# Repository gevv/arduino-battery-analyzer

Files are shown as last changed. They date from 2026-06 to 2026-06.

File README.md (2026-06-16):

# Arduino Battery Analyzer

This project is an Arduino-based battery analyzer designed for measuring battery capacity and estimating internal resistance + constant current. It can be used not only for single-cell 18650 Li-ion batteries, but also for other rechargeable batteries and battery packs up to approximately 20 V, depending on the voltage divider, load resistor, MOSFET, cooling, and calibration settings.

Related article/project page:
https://320volt.com/arduino-pil-analizoru/

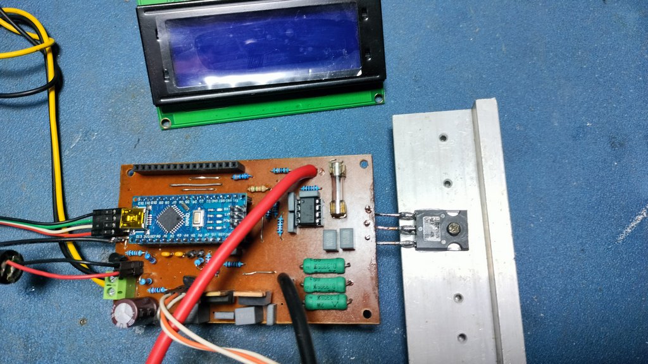
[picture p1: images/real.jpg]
Arduino Battery Analyzer Prototype


## Features

* Power requirements: 12 V, 250 mA
* Input voltage: 0.8-20 V, measurement resolution 0.01 V
* Can be adapted for other batteries or battery packs up to approximately 20 V
* Battery  Capacity meter
* Constant current load
* Internal resistance meter
* Discharge current: 0,01-2,55 A
* Control: 4 buttons, 20x4 character LCD
* LM35 Fan control (optinal)

## LCD Menu and Measurement Screens

The project uses a 20x4 character LCD screen for menu navigation, capacity measurement, constant current load testing, internal resistance measurement, and device settings.

### Main Menu

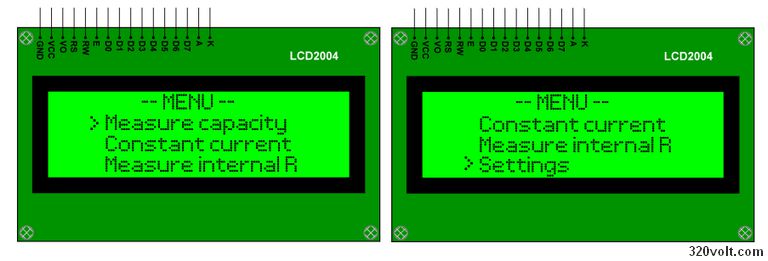
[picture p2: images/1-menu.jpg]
Main Menu


### Capacity Measurement

This mode is used to discharge the connected battery with a selected current and calculate the measured capacity.

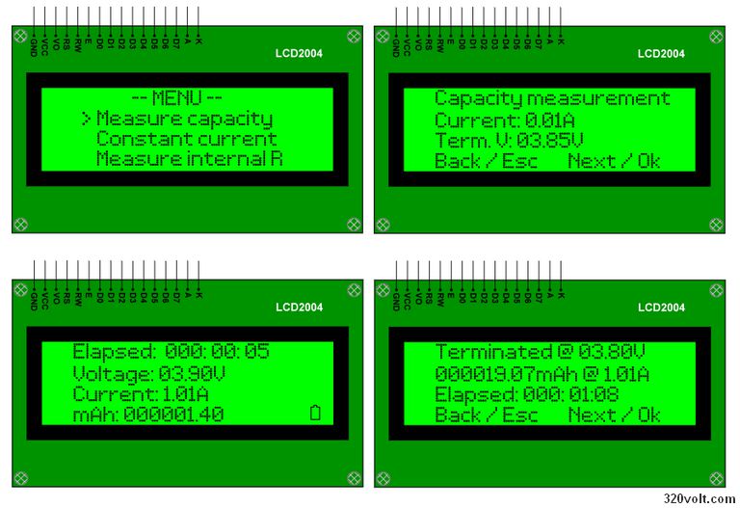
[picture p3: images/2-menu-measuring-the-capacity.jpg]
Capacity Measurement Menu


### Constant Current Mode

This mode allows the circuit to operate as a constant current electronic load.

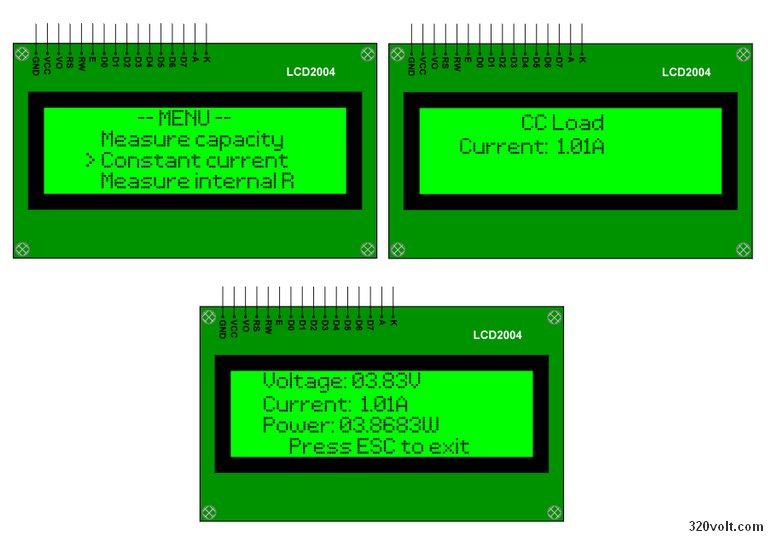
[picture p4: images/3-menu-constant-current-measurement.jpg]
Constant Current Measurement


### Internal Resistance Measurement

This mode estimates the internal resistance of the battery by comparing voltage values under different load current conditions.

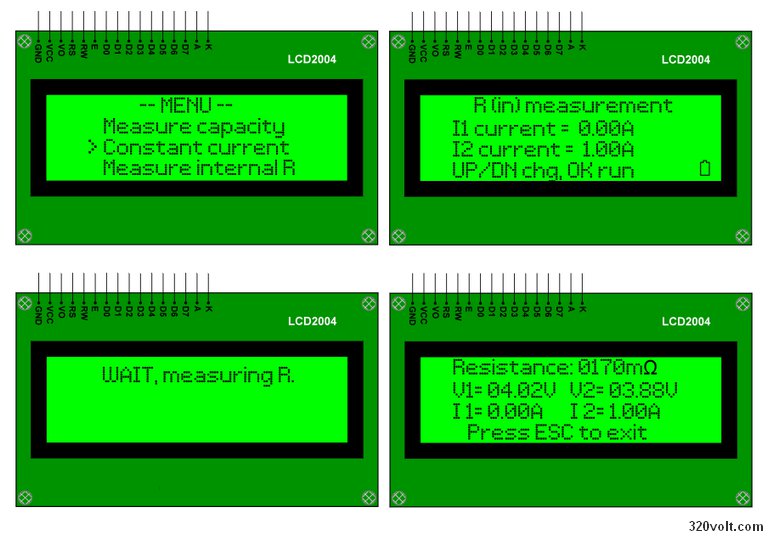
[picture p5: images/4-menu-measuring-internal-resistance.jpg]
Internal Resistance Measurement


### Settings Menu

The settings menu includes options such as sound, ADC offset compensation, and saving calibration values to EEPROM.

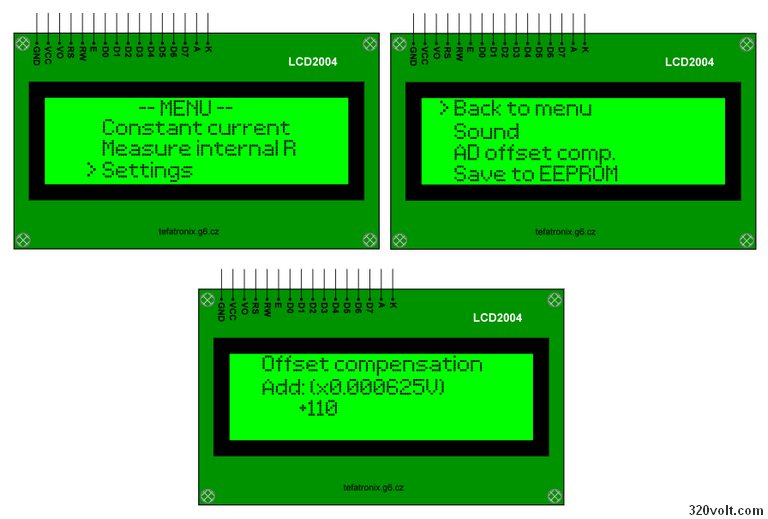
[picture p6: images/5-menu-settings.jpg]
Settings Menu


## Hardware

* Arduino Nano / ATmega328P
* Battery holder or external battery connection terminals
* Load resistors
* MOSFET driver circuit
* LCD screen
* Voltage measurement divider circuit
* Current measurement circuit
* Cooling fan for load resistors and MOSFET

## Schematic

The schematic below shows the Arduino Nano connections, LCD interface, voltage divider, MOSFET load stage, current sensing section, buzzer, fan output, and power supply regulators.

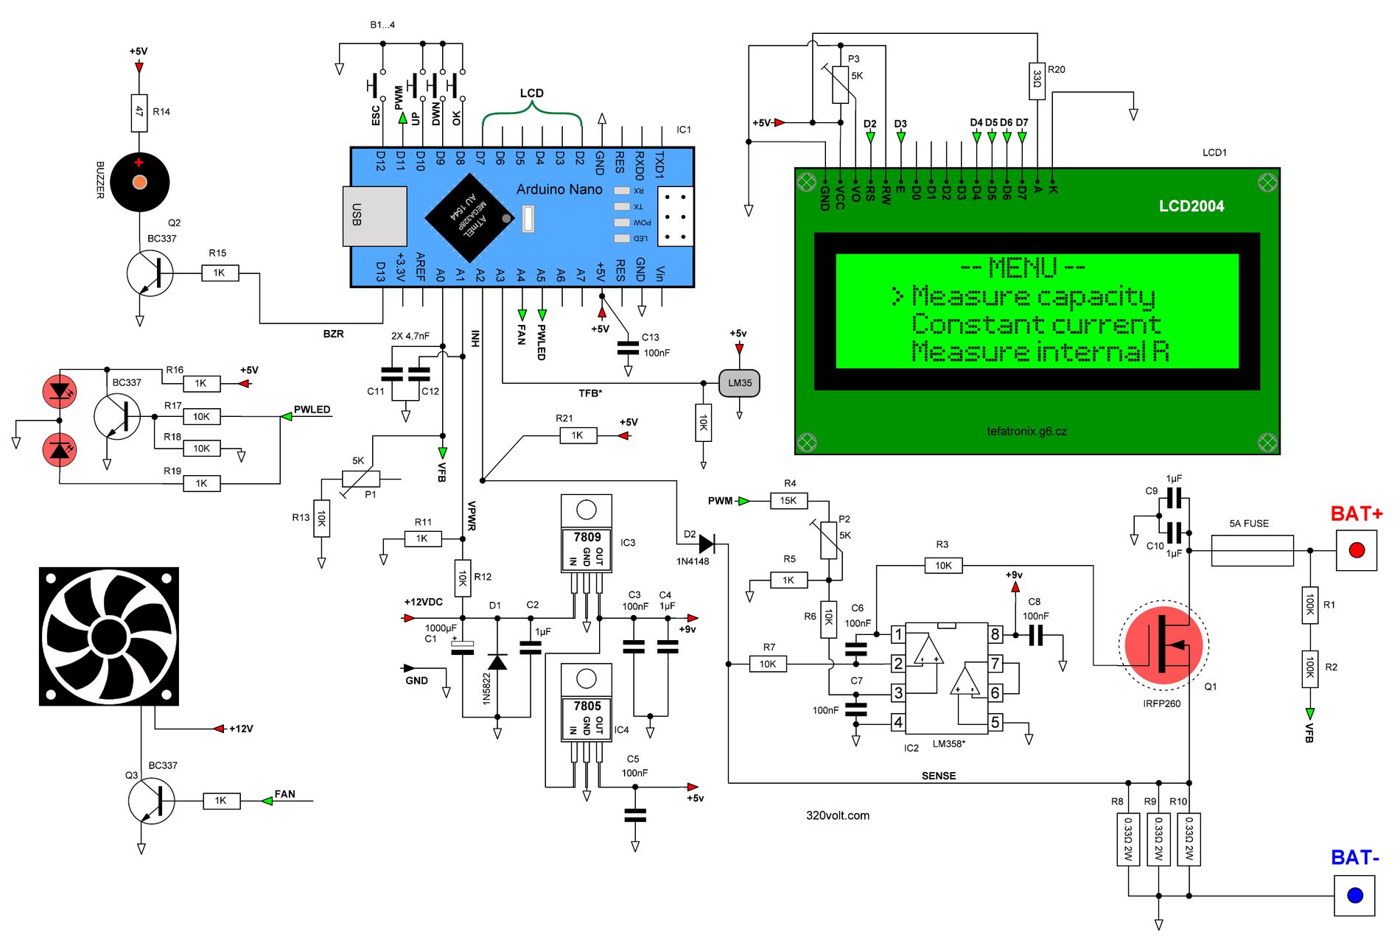
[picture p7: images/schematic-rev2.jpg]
Arduino Battery Analyzer Schematic


## PCB Layout

The PCB layout includes the Arduino Nano, LCD connector, MOSFET load section, resistor load bank, voltage measurement input, current sense path, fan output, and power supply section.

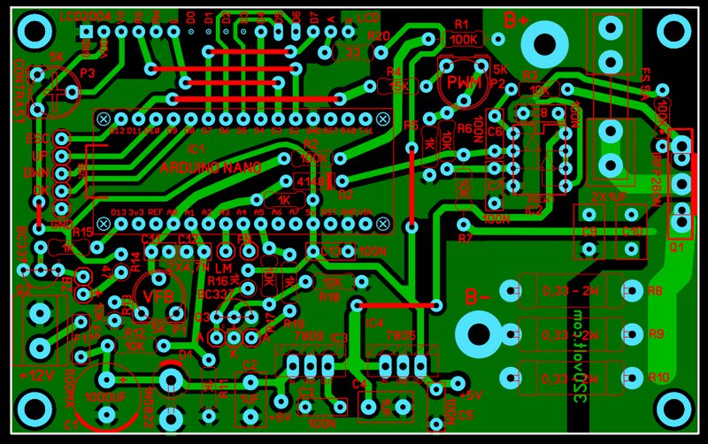
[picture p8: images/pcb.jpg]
Arduino Battery Analyzer PCB


## Important Note

This project is for educational and testing purposes only. When working with Li-ion batteries, lead-acid batteries, NiMH packs, or other rechargeable batteries, caution must be exercised against short circuits, overcurrent, reverse polarity, overheating, and incorrect voltage divider calibration.

For battery voltages higher than a single Li-ion cell, the voltage divider, load resistor power rating, MOSFET voltage/current rating, heat dissipation, and firmware calibration values must be checked and adjusted before use.

The maximum usable battery voltage depends on the voltage divider ratio, ADC input limits, MOSFET rating, load resistor power rating, fuse rating, PCB trace current capacity, and cooling performance.

## Credits

Original project:
https://tefatronix.g6.cz/display.php?page=batmeter

Original author:
F. Štefanec

Related article/project page:
https://320volt.com/arduino-pil-analizoru/

This Arduino Nano version is based on / adapted from the original rechargeable battery analyzer project.

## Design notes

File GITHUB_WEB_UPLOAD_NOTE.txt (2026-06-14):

GitHub Web Upload Note

Do not upload this ZIP file as a single file if you want GitHub to display the project folders.

1. Extract this ZIP on your computer.
2. Open the extracted folder.
3. On GitHub, create a new repository.
4. Use Add file > Upload files.
5. Drag and drop the CONTENTS of this folder into GitHub.
6. Commit the upload.

Recommended repository name:
arduino-battery-analyzer

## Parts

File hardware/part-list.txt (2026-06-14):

*
* Name	Value	Comment
*
C1	1000uF	16V
C2	1uF	Polyester, non-polarized
C3	100nF	
C4	1uF	Polyester, non-polarized
C5	100nF	
C6	100nF	Multilayer
C7	100nF	Multilayer
C8	100nF	
C9	1uF	Polyester, non-polarized
C10	1uF	Polyester, non-polarized
C11	4,7nF	MULTILAYER
C12	4,7nF	MULTILAYER
C13	100nF	
D1	1N5822	
D2	1N4148	
F1	500MA	FUSE OR JUMPER
F2	5A	    FUSE OR JUMPER (1.5mm)
B1	Button
B2	Button
B3	Button
B4	Button
IC1	ARDUINO NANO	
IC2	LM358	
IC3	7809	TO220
IC4	7805	TO220
LCD	20X4	LCD2004
P1	5K	TRIMPOT
P2	5K	TRIMPOT
P3	5K	TRIMPOT
Q1	IRFP260	
Q2	BC337	
Q3	BC337	
R1	100K	%1
R2	100K	%1
R3	10K	
R4	15K	%1
R5	1K	%1
R6	10K	%1
R7	10K	%1
R8	0.33 OHM	2W
R9	0.33 OHM	2W
R10	0.33 OHM 	2W
R11	1K	%1
R12	10K	%1
R13	10K	%1
R14	47 OHM	
R15	1K	
R16	1K	
R17	10K	
R18	10K	
R19	1K	
R20	33 OHM	

OPTINAL
LM35 + 1OK (OUT/GND)
BC337 + 1K (FAN)

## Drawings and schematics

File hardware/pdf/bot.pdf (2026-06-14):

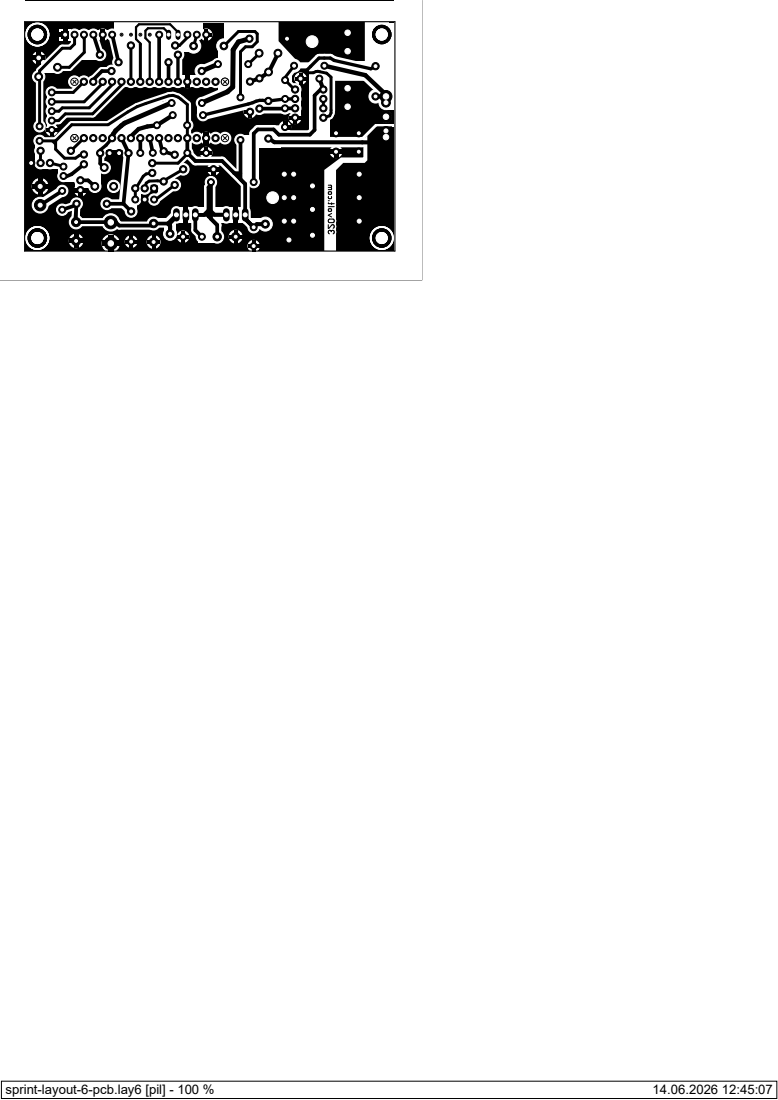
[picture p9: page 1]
sprint-layout-6-pcb.lay6 [pil] - 100 %

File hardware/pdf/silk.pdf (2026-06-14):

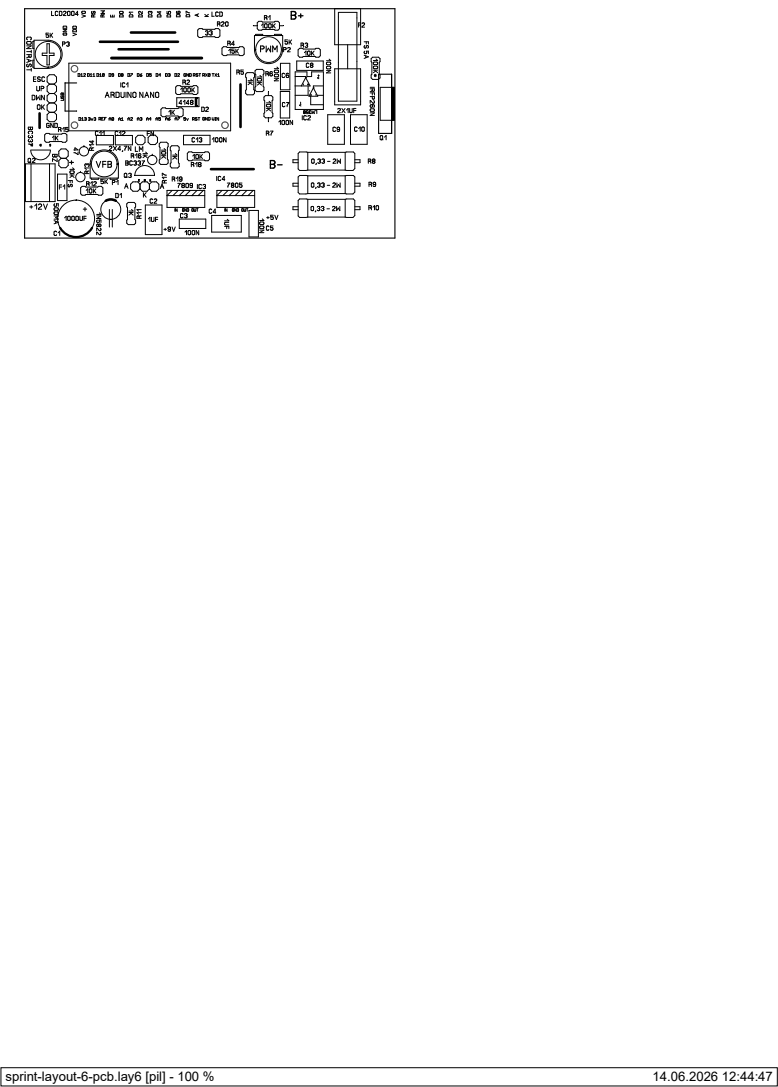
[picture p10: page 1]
sprint-layout-6-pcb.lay6 [pil] - 100 %

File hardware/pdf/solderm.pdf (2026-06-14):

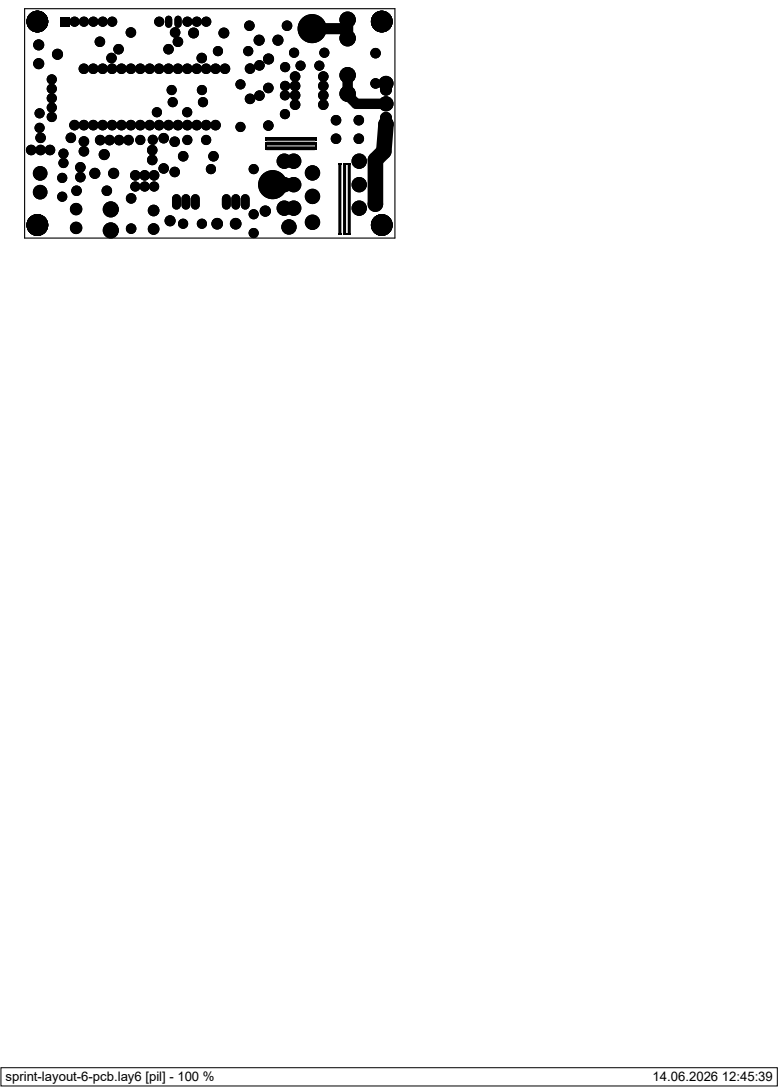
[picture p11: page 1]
sprint-layout-6-pcb.lay6 [pil] - 100 %

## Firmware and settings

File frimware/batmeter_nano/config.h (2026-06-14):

/**
    Battery analyzer - Arduino Nano port
    Original: (c) 2016-2017 F. Štefanec
    Arduino Nano port: 2024

    ATmega328P pin mapping is IDENTICAL between the original board and Arduino Nano.
    Only the build system changes (AVR-C → Arduino framework).

    Original schematic pin assignments are preserved 1:1.
**/

#ifndef CONFIG_INCLUDED
#define CONFIG_INCLUDED

/// Language
//#define LANG_CZ
#define LANG_EN

// ─── LCD pin / port definitions ──────────────────────────────────────────────
// LCD is connected to PORTD (data + control), same as original schematic.
#define LCD_DPORT  PORTD
#define LCD_CPORT  PORTD
#define LCD_DDDR   DDRD
#define LCD_CDDR   DDRD
#define LCD_E      PD3    // Arduino D3
#define LCD_RS     PD2    // Arduino D2
#define LCD_D4     PD4    // Arduino D4
#define LCD_D5     PD5    // Arduino D5
#define LCD_D6     PD6    // Arduino D6
#define LCD_D7     PD7    // Arduino D7
#define DISPSIZE   6      // 20x4 display, do not modify

// ─── Keyboard ────────────────────────────────────────────────────────────────
#define DEBOUNCE_VAL   6    // 6 × 4ms ≈ 24 ms
#define REPEAT_PERIOD  30   // 30 × 4ms = 120 ms
#define REPEAT_DELAY   250  // 250 × 4ms = 1000 ms

// ─── ADC / measurement ───────────────────────────────────────────────────────
#define DEFAULT_OFFSET_COMP  110
#define RIN_PREAVG_COUNT     8
#define CAP_PREAVG_COUNT     32
#define DEFAULT_SETTINGS     0

// ─── Temperature / LM35 ──────────────────────────────────────────────────────
/// Uncomment the next line only if the LM35 sensor is installed on TFB / A3.
/// If the sensor is not installed, leaving it enabled can cause false thermal shutdown.
//#define LM35_INSTALLED
#define TEMP_AD_FAN_START  512   // ~55 °C
#define TEMP_AD_FAN_STOP   446   // ~48 °C
#define TEMP_AD_FAULT      725   // ~78 °C  → emergency halt

// ─── Button pins (PORTB) ─────────────────────────────────────────────────────
// Original: PINB / PORTB
#define BTN_PIN   PINB
#define BTN_PORT  PORTB

#define BTN_ESC_PIN   PB4   // Arduino D12
#define BTN_UP_PIN    PB2   // Arduino D10
#define BTN_DOWN_PIN  PB1   // Arduino D9
#define BTN_OK_PIN    PB0   // Arduino D8

// ─── INHIBIT pin (PC2 = Arduino A2) ──────────────────────────────────────────
#define INHIBIT_PIN   PC2
#define INHIBIT_PORT  PORTC
#define INHIBIT_DDR   DDRC

// ─── Buzzer (PB5 = Arduino D13) ──────────────────────────────────────────────
// NOTE: D13 also has the built-in LED. Disconnect or ignore LED flicker.
#define BUZZER_PIN   PB5
#define BUZZER_PORT  PORTB
#define BUZZER_DDR   DDRB

// ─── ADC channel mux values ──────────────────────────────────────────────────
#define MUX_BATT_VOLTAGE    (0)                   // ADC0 = A0
#define MUX_SUPPLY_VOLTAGE  (1<<MUX0)             // ADC1 = A1
#define MUX_TEMPERATURE     (0b011)               // ADC3 = A3

// ─── Fan (PC4 = Arduino A4) ──────────────────────────────────────────────────
#define FAN_PIN   PC4
#define FAN_PORT  PORTC
#define FAN_DDR   DDRC

// ─── Power LED (PC5 = Arduino A5) ────────────────────────────────────────────
#define LED_PIN   PC5
#define LED_DDR   DDRC
#define LED_PORT  PORTC

// ─── Beep lengths (timer 0 ticks @ 2 kHz / 8 = 250 Hz effective) ─────────────
#define BEEP_LEN_BUTTON    10
#define BEEP_LEN_FINISHED  250
#define BEEP_LEN_REPEAT    5
#define BEEP_LEN_START     5

#endif // CONFIG_INCLUDED

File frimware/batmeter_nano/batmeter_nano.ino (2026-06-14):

/**
Battery Analyzer v1.4.0 — Arduino Nano port

Original code: (c) 2016-2017 F. Štefanec

Arduino Nano port: 2026

This firmware is an Arduino Nano port / modified version of the
original rechargeable battery analyzer project.

Original project page: https://tefatronix.g6.cz/display.php?page=batmeter

Original author: F. Štefanec

Original code license: GNU GPL v2 or later, unless otherwise noted by the original author.

Related article/project page: https://320volt.com/arduino-pil-analiz-cihazi

Hardware note:
  Hardware connections are intended to match the original ATmega328P
  design. Arduino Nano uses the same ATmega328P MCU, so register names
  such as TCCR0B, OCR2A, ADMUX, etc. remain unchanged.

Changes from original:
  - main() -> setup() + loop()
  - _delay_ms/_delay_us -> wait_ms()/delayMicroseconds()
  - avr/io.h / util/delay.h -> Arduino.h
  - avr/eeprom.h functions are still used directly
  - avr/pgmspace.h PROGMEM is still used directly
  - Watchdog: wdt.h included for Arduino-safe macros
  - ISR declarations retained as-is

Pin summary (Arduino Nano digital / analog labels):
  D2  = LCD RS
  D3  = LCD E
  D4-D7 = LCD data

  D8  = BTN OK
  D9  = BTN DOWN
  D10 = BTN UP
  D12 = BTN ESC

  D11 = PWM output (OC2A, PB3)
  D13 = Buzzer (PB5) - shares built-in LED

  A0  = Battery voltage ADC
  A1  = Supply voltage ADC
  A2  = INHIBIT output
  A3  = Temperature (LM35) ADC
  A4  = FAN output
  A5  = Power LED output

*/


// ─── Core AVR headers (available inside Arduino framework) ───────────────────
#include <Arduino.h>
#include <avr/interrupt.h>
#include <avr/eeprom.h>
#include <avr/pgmspace.h>
#include <avr/wdt.h>
#include <util/atomic.h>


// Save reset cause and disable watchdog as early as possible.
// This is important on Arduino Nano/Optiboot-style bootloaders when WDT is used.
uint8_t mcusr_mirror __attribute__((section(".noinit")));
void get_mcusr(void) __attribute__((section(".init3")));
void get_mcusr(void)
{
    mcusr_mirror = MCUSR;
    MCUSR = 0;
    wdt_disable();
}

// ─── Project headers ─────────────────────────────────────────────────────────
#include "config.h"
#include "global_defines.h"
#include "lcd.h"
#include "string_table.h"
#include "lcd_customchars.h"
#include "digits.h"
#include "menu.h"

// ─── Omega character position in CGRAM ───────────────────────────────────────
#define OMEGA_CHAR 5

// ════════════════════════════════════════════════════════════════════════════
//  GLOBAL VARIABLES  (identical to original main.h)
// ════════════════════════════════════════════════════════════════════════════

uint8_t x, y, z;

uint8_t ad_preavg_count;
volatile uint8_t stat, stat2;
volatile uint8_t discharge_stop_request = 0;
volatile uint8_t temp_fault_request = 0;
uint8_t settings;
uint8_t submenu_stat = 0;
uint8_t field = 0;
uint8_t menu_pos = 1, old_menu_pos = 1, menu_pos2, old_menu_pos2;
volatile uint8_t beep_counter, old_beep_counter;
uint8_t rin_current_choice = 0;
const uint8_t rin_current1[10] PROGMEM = {0,  25,   0,  50,   0, 100, 150,   0,  50,   0};
const uint8_t rin_current2[10] PROGMEM = {25, 50,  50, 100, 100, 200, 250, 200, 250, 250};
uint8_t led_state1 = 2;
uint8_t led_state2 = 0;
volatile uint16_t led_blink_time = 0;
uint8_t last_option = 0;
volatile uint8_t fan_control = 0;

volatile uint8_t  seconds;
volatile uint8_t  minutes;
volatile uint8_t  hours;
unsigned long long elapsed_secs = 0;
uint8_t tim0_sw_pre;
uint8_t tim0_even = 0;
uint16_t tim0_blink_counter = 0;

uint8_t buttons_old_pin;
volatile uint8_t buttons;
uint8_t buttons_old;
uint8_t buttons_pressed;
uint8_t button_repeat_counter;
uint8_t btn_debounce = 0;

volatile uint8_t batt_icon = 0;
char buf[20];
char disch_power_str[8];
uint8_t display_mode;

uint16_t end_voltage   = DEFAULT_TERM_VOLTAGE;
uint16_t term_voltage  = DEFAULT_TERM_VOLTAGE;
volatile uint16_t adc_voltage       = 0;
uint16_t disp_voltage  = 0;
volatile uint16_t supp_voltage      = 0;
volatile uint16_t temperature_value = 0;
uint16_t volt_buf[64];
uint8_t  ad_buf_ptr = 0;
uint16_t ad_avg_buf[32];
uint8_t  ad_avg_buf_ptr;
uint8_t  ad_throwaway;
uint8_t  pwm_current = 1;
uint16_t v1, v2, i1, i2 = 25, rin;

unsigned long long mAs    = 0;
unsigned long long mAh100 = 0;
unsigned long long mWsx10 = 0;

int8_t offset_comp;

// ════════════════════════════════════════════════════════════════════════════
//  FORWARD DECLARATIONS
// ════════════════════════════════════════════════════════════════════════════

void terminate_discharge();
void print_discharge_result();
void calculate_mAh();
void calculate_mWsx10();
void mAh_string(char *buf);
void mWh_string(char *buf);
void time_string(char *buf);
void voltage_string(char *buf, uint16_t voltage);
void adjust_term_voltage(int16_t delta);
void current_string(char *buf, uint8_t current);
void rin_string(char *buf, uint16_t rin_centi_ohm);
void watt_string(char *buf, uint16_t voltage, uint8_t current);
void display_prog();
void display_ccload();
void enable_1s_timer();
void fast_1s_timer();
void disable_1s_timer();
void set_current(uint8_t current);
void rin_test();
void lcd_print_pmem(const char *data, uint8_t length);
void lcd_print_pmem_setpos(const char *data, uint8_t len, uint8_t column, uint8_t line);
uint8_t get_buttons();
void clear_time();
void enable_wdt();
void disable_wdt();
void deconf_regs();
void halt_error();
void cap_submenu();
void cc_submenu();
void rin_submenu();
void settings_submenu();
void escape_to_menu();
void print_menu(const char **items, uint8_t position);
void service_menu();
void disp_menu();
void print_settings_submenu(uint8_t cursor_pos);
void calib_menu();
void save_eeprom();
void set_offset_comp();
void load_eeprom();
void print_temp_error();

// Busy-wait delay that does not depend on Arduino Timer0 interrupts.
// The sketch reconfigures Timer0 for its own 2 kHz ISR, so Arduino delay()/millis()
// must not be used in this project.
static void wait_ms(uint16_t ms)
{
    while (ms--) {
        delayMicroseconds(1000);
    }
}

// ════════════════════════════════════════════════════════════════════════════
//  INTERRUPT SERVICE ROUTINES
// ════════════════════════════════════════════════════════════════════════════

/** Timer 1 Compare ISR — 1 Hz time counter **/
ISR(TIMER1_COMPA_vect)
{
    if (stat & stat_disch_enabled)
    {
        stat |= stat_display_prog;
        seconds++;
        if (seconds >= 60) { seconds = 0; minutes++; }
        if (minutes >= 60) { minutes = 0; hours++;   }
        if (hours == 255)  { stat &= ~stat_disch_enabled; stat |= stat_term_wait; }
    }
    if (stat & stat_ccload_enabled) stat |= stat_ccload_display;
    batt_icon++;
    if (batt_icon > 4) batt_icon = 0;
}

/** ADC conversion complete ISR **/
ISR(ADC_vect)
{
    if (ad_throwaway == 0)
    {
        ad_avg_buf[ad_avg_buf_ptr] = ADC;
        ad_avg_buf_ptr++;

        if (ad_avg_buf_ptr >= ad_preavg_count)
        {
            ad_avg_buf_ptr = 0;
            uint8_t  array_ptr, new_admux;
            uint16_t ADC_VALUE = 0;
            uint8_t  i;

            for (i = 0; i < ad_preavg_count; i++) ADC_VALUE += ad_avg_buf[i];
            ADC_VALUE /= ad_preavg_count;

            array_ptr = ad_buf_ptr;
            new_admux = ADMUX & ~((1<<MUX0)|(1<<MUX1)|(1<<MUX2)|(1<<MUX3));

            if (array_ptr < 32)
            {
                volt_buf[array_ptr] = ADC_VALUE;
                uint8_t  j = 0;
                uint16_t adc_volt_temp = 0;
                for (j = 0; j < 32; j++) adc_volt_temp += volt_buf[j];
                adc_voltage = adc_volt_temp;

                if (offset_comp != 0)
                {
                    uint8_t abs_val = (offset_comp < 0) ? (uint8_t)(-1 * offset_comp) : (uint8_t)(offset_comp);
                    if ((offset_comp != (int8_t)abs_val) && (adc_voltage > abs_val))
                        adc_voltage -= abs_val;
                    else
                        adc_voltage += offset_comp;
                }
                adc_voltage /= 16;
                if (adc_voltage > 2500) adc_voltage = 0;
                if (offset_comp > 0 && adc_voltage <= 1 + offset_comp / 16) adc_voltage = 0;
            }
            if (array_ptr == 32) supp_voltage      = ADC_VALUE;
            if (array_ptr == 33) temperature_value = ADC_VALUE;

            ad_buf_ptr++;
            if (ad_buf_ptr == 34) ad_buf_ptr = 0;

            if (ad_buf_ptr == 0)  { new_admux |= MUX_BATT_VOLTAGE;    ad_throwaway = 5; ADMUX = new_admux; }
            if (ad_buf_ptr == 32) { new_admux |= MUX_SUPPLY_VOLTAGE;  ad_throwaway = 5; ADMUX = new_admux; }
            if (ad_buf_ptr == 33) { new_admux |= MUX_TEMPERATURE;     ad_throwaway = 5; ADMUX = new_admux; }
        }
    }
    else
    {
        ad_throwaway--;
        delayMicroseconds(1);
    }
}

/** Timer 0 Compare ISR — 2 kHz: button scan, buzzer, LED blink, fan, ADC trigger **/
ISR(TIMER0_COMPA_vect)
{
    tim0_sw_pre++;
    if (tim0_sw_pre > 7)
    {
        z  = ~BTN_PIN;
        z &= (1<<BTN_ESC_PIN)|(1<<BTN_OK_PIN)|(1<<BTN_DOWN_PIN)|(1<<BTN_UP_PIN);
        y  = 0;
             if ((z & (1<<BTN_ESC_PIN))  != 0) y |= BTN_ESC;
        else if ((z & (1<<BTN_UP_PIN))   != 0) y |= BTN_UP;
        else if ((z & (1<<BTN_DOWN_PIN)) != 0) y |= BTN_DOWN;
        else if ((z & (1<<BTN_OK_PIN))   != 0) y |= BTN_OK;

        if (btn_debounce == 0) { buttons = y; btn_debounce = DEBOUNCE_VAL; }
        else btn_debounce--;

        if (buttons > 0 && (buttons != buttons_old_pin) && beep_counter == 0)
            beep_counter = BEEP_LEN_BUTTON;
        buttons_old_pin = buttons;

        if (y == 0) { button_repeat_counter = 0; }
        else
        {
            button_repeat_counter++;
            if (button_repeat_counter == REPEAT_DELAY)
            {
                buttons_old = 0;
                button_repeat_counter -= REPEAT_PERIOD;
                beep_counter = BEEP_LEN_REPEAT;
            }
        }

        if ((stat & stat_disch_enabled) > 0 && (adc_voltage <= term_voltage))
        {
            // Do not run LCD/calculation routines inside the ISR.
            // Main loop will stop the discharge safely.
            discharge_stop_request = 1;
        }

        if (beep_counter > 0) beep_counter--;
        tim0_sw_pre = 0;
    }

    // Buzzer
    if      (beep_counter == 0)                         BUZZER_PORT &= ~(1<<BUZZER_PIN);
    else if (settings & settings_sound_on)              BUZZER_PORT ^=  (1<<BUZZER_PIN);

    delayMicroseconds(1);

    // Trigger next ADC conversion
    ADCSRA |= (1<<ADSC);

    // Power LED blink
    tim0_blink_counter++;
    if (tim0_blink_counter >= 1000) tim0_blink_counter = 0;
    tim0_even++;
    if (tim0_even >= 2) tim0_even = 0;

    if (led_blink_time <= tim0_blink_counter)
    {
        if (led_state1 == 0 || (led_state1 == 1 && tim0_even == 1)) LED_PORT &= ~(1<<LED_PIN);
        else                                                          LED_PORT |=  (1<<LED_PIN);
    }
    else
    {
        if (led_state2 == 0 || (led_state2 == 1 && tim0_even == 1)) LED_PORT &= ~(1<<LED_PIN);
        else                                                          LED_PORT |=  (1<<LED_PIN);
    }

    // Temperature-based fan control
#ifdef LM35_INSTALLED
    if (temperature_value < TEMP_AD_FAN_STOP) fan_control &= ~2;
    if (temperature_value > TEMP_AD_FAN_START) fan_control |= 2;
    if (temperature_value > TEMP_AD_FAULT)
    {
        // Keep the ISR short: stop load/fan on immediately, show error in loop().
        set_current(0);
        FAN_PORT |= (1<<FAN_PIN);
        temp_fault_request = 1;
    }
    if ((fan_control & 2) != 0) FAN_PORT |= (1<<FAN_PIN); else FAN_PORT &= ~(1<<FAN_PIN);
#else
    if ((fan_control & 1) != 0) FAN_PORT |= (1<<FAN_PIN); else FAN_PORT &= ~(1<<FAN_PIN);
#endif
}

// ════════════════════════════════════════════════════════════════════════════
//  ARDUINO setup()  —  replaces original int main()  initialisation block
// ════════════════════════════════════════════════════════════════════════════
void setup()
{
    cli();

    // Port initialisation
    PORTD = 0; PORTC = 0; PORTB = 0;
    DDRD  = 0; DDRC  = 0; DDRB  = 0;

    // Button pull-ups
    BTN_PORT |= (1<<BTN_ESC_PIN)|(1<<BTN_DOWN_PIN)|(1<<BTN_UP_PIN)|(1<<BTN_OK_PIN);

    // Outputs
    FAN_DDR    |= (1<<FAN_PIN);
    BUZZER_DDR |= (1<<BUZZER_PIN);
    LCD_DDDR   |= (1<<LCD_D7)|(1<<LCD_D6)|(1<<LCD_D5)|(1<<LCD_D4);
    LCD_CDDR   |= (1<<LCD_E)|(1<<LCD_RS);
    INHIBIT_PORT |= (1<<INHIBIT_PIN);
    INHIBIT_DDR  |= (1<<INHIBIT_PIN);
    DDRB |= (1<<PB3);   // PWM pin (OC2A)
    LED_DDR  |= (1<<LED_PIN);
    LED_PORT |= (1<<LED_PIN);   // keep power LED in its initial ON state

    load_eeprom();
    ad_preavg_count = CAP_PREAVG_COUNT;

    // LCD init
    lcd_init();
    lcd_send(LCD_FUNCSET | LCD_FUNCSET_2LINES);
    lcd_send(LCD_ONOFF   | LCD_ONOFF_DISPLAY);
    lcd_send(LCD_CLEAR);
    wait_ms(5);
    lcd_send(LCD_ENTRYMODE | LCD_ENTRYMODE_INCREMENT);

    // Watchdog reset check
    if (mcusr_mirror & (1<<WDRF))
    {
        set_current(0);
        disable_1s_timer();
        lcd_clear();
        wdt_disable();
        lcd_print_pmem_setpos(str_em_shdn,    20, 0, 0);
        lcd_print_pmem_setpos(str_em_shdn_wd0, 20, 0, 1);
        lcd_print_pmem_setpos(str_em_shdn_wd1, 20, 0, 2);
        mcusr_mirror &= ~(1<<WDRF);
        halt_error();
    }

    // Custom characters
    lcd_customchar(0, (char*)customchar1);
    lcd_customchar(1, (char*)customchar2);
    lcd_customchar(2, (char*)customchar3);
    lcd_customchar(3, (char*)customchar4);
    lcd_customchar(4, (char*)customchar5);
    lcd_customchar(5, (char*)customchar6);

    // Welcome screen
    lcd_print_pmem_setpos(str_welcome1,        20, 0, 0);
    lcd_print_pmem_setpos(str_welcome2,        20, 0, 1);
    lcd_print_pmem_setpos(str_firmware_version,20, 0, 3);
    for (z = 0; z < 250; z++) wait_ms(8);   // ~2 s

    beep_counter = BEEP_LEN_START;
    lcd_clear();

    // Timer 0 — 2 kHz CTC (button scan, buzzer)
    TCCR0B = (1<<CS01)|(1<<CS00);   // prescaler 1:64
    TCCR0A = (1<<WGM01);            // CTC mode
    OCR0A  = 124;                   // 16M / 64 / 125 = 2000 Hz

    // Timer 1 — elapsed time base. It is configured here but its interrupt
    // is enabled only when a capacity / CC-load test actually starts.
    TCCR1A = 0;
    TCCR1B = 0;
    TCNT1  = 0;
    OCR1A  = TIME_PRESCALER_1000ms; // 16M / 256 / 62500 = 1 Hz
    TCCR1B = (1<<WGM12)|(1<<CS12);  // CTC, prescaler 1:256

    TIMSK0 = (1<<OCIE0A);
    TIMSK1 = 0;                     // enabled by enable_1s_timer()

    // Timer 2 — PWM for load current control (OC2A = PB3 = D11)
    OCR2A  = 0;
    TCCR2A = (1<<COM2A1)|(1<<WGM20); // phase-correct PWM, non-inverting
    TCCR2B = (1<<CS20);              // no prescaler, phase-correct PWM → ~31.37 kHz

    // ADC setup — internal 1.1 V reference, interrupt-driven
    ADMUX  = (1<<REFS0)|(1<<REFS1);  // 1.1 V ref, ADC0 input
    ADCSRA = (1<<ADEN)|(1<<ADPS2)|(1<<ADPS1)|(1<<ADPS0)|(1<<ADIE);
    ADCSRA |= (1<<ADSC);             // start first conversion

    LED_DDR |= (1<<LED_PIN);
    led_state1     = 2;
    led_state2     = 0;
    led_blink_time = 0;

    sei();
    wait_ms(5);

    lcd_clear();

    // Show main menu
    stat  |= stat_inside_menu;
    stat2 |= stat2_redraw_menu;
    lcd_print_pmem_setpos(str_select0, 10, 5, 0);
    set_current(0);
}

// ════════════════════════════════════════════════════════════════════════════
//  ARDUINO loop()  —  replaces original while(1) main loop
// ════════════════════════════════════════════════════════════════════════════
void loop()
{
#ifdef LM35_INSTALLED
    if (temp_fault_request)
    {
        cli();
        temp_fault_request = 0;
        sei();
        wdt_disable();
        deconf_regs();
        FAN_PORT |= (1<<FAN_PIN);
        print_temp_error();
        halt_error();
    }
#endif

    if (discharge_stop_request)
    {
        cli();
        discharge_stop_request = 0;
        sei();
        if (stat & stat_disch_enabled)
        {
            terminate_discharge();
        }
    }

    if (stat2 & stat2_redraw_menu)
    {
        lcd_print_pmem_setpos(str_select0, 10, 5, 0);
        lcd_setcursor(2,1); strcpy_P(buf, str_menu_items[menu_pos2+0]); lcd_sendstring(buf, 18);
        lcd_setcursor(2,2); strcpy_P(buf, str_menu_items[menu_pos2+1]); lcd_sendstring(buf, 18);
        lcd_setcursor(2,3); strcpy_P(buf, str_menu_items[menu_pos2+2]); lcd_sendstring(buf, 18);
        stat2 &= ~stat2_redraw_menu;
    }

    if (stat & stat_inside_menu)
    {
        led_blink_time = 0;
        if (OCR2A != 0) set_current(0);
        disp_menu();
    }

    if (stat & stat_display_prog)
    {
        led_blink_time = 200;
        led_state2 = 0;
        calculate_mAh();
        calculate_mWsx10();
        display_prog();
        stat &= ~(stat_display_prog);
    }

    if (stat & stat_ccload_display)
    {
        led_blink_time = 200;
        led_state2 = 0;
        display_ccload();
        stat &= ~(stat_ccload_display);
    }

    if (stat & stat_term_wait)
    {
        led_blink_time = 500;
        led_state2 = 0;
        buttons_pressed = get_buttons();
        if (buttons_pressed & BTN_ESC)
        {
            disable_wdt();
            lcd_clear();
            print_menu(str_menu_items, menu_pos2);
            stat &= ~(stat_term_wait);
            stat |= stat_inside_menu;
        }
        if ((buttons_pressed & BTN_OK || buttons_pressed & BTN_UP || buttons_pressed & BTN_DOWN) && (last_option == 0))
        {
            display_mode = display_mode == 1 ? 0 : 1;
            print_discharge_result();
        }
    }

    if (stat & (stat_ccload_enabled | stat_disch_enabled))
    {
        watt_string(disch_power_str, disp_voltage, pwm_current);
        buttons_pressed = get_buttons();

        if (buttons_pressed & BTN_ESC)
        {
            set_current(0);
            if (stat & stat_ccload_enabled)
            {
                stat &= ~stat_ccload_enabled;
                disable_wdt();
                escape_to_menu();
            }
            else if (stat & stat_disch_enabled)
            {
                terminate_discharge();
            }
        }

        if ((buttons_pressed & BTN_OK) && (stat & stat_ccload_enabled))
            display_mode = display_mode == 1 ? 0 : 1;

        else if ((buttons_pressed & (BTN_UP|BTN_DOWN)) && (stat & stat_ccload_enabled))
        {
            if ((buttons_pressed & BTN_UP)   && pwm_current < 255) { set_current(0); pwm_current++; set_current(pwm_current); }
            if ((buttons_pressed & BTN_DOWN) && pwm_current > 1)   { set_current(0); pwm_current--; set_current(pwm_current); }
            display_ccload();
        }

        if ((stat & stat_disch_enabled) && (buttons_pressed & BTN_OK || buttons_pressed & BTN_UP || buttons_pressed & BTN_DOWN))
        {
            display_mode = display_mode == 1 ? 0 : 1;
            display_prog();
        }
    }

    wdt_reset();   // replaces asm("WDR")
}

// ════════════════════════════════════════════════════════════════════════════
//  HELPER / UTILITY FUNCTIONS  (identical logic to original)
// ════════════════════════════════════════════════════════════════════════════

void set_current(uint8_t current)
{
    OCR2A = current;
    if (current == 0) { INHIBIT_PORT |= (1<<INHIBIT_PIN); fan_control &= ~1; }
    else              { INHIBIT_PORT &= ~(1<<INHIBIT_PIN); fan_control |= 1; }
}

void halt_error()
{
    cli();
    set_current(0);
    disable_1s_timer();
    disable_wdt();
    while (1);
}

void clear_time() { hours = 0; minutes = 0; seconds = 0; }

void enable_wdt()
{
    wdt_reset();
    wdt_enable(WDTO_500MS);
}

void disable_wdt()
{
    wdt_reset();
    wdt_disable();
}

void enable_1s_timer()
{
    cli();
    TCCR1A = 0;
    TCCR1B = 0;
    TCNT1  = 0;
    OCR1A  = TIME_PRESCALER_1000ms;
    TIFR1  = (1<<OCF1A);            // clear a pending compare flag
    TCCR1B = (1<<WGM12)|(1<<CS12);  // CTC, prescaler 1:256
    TIMSK1 |= (1<<OCIE1A);
    sei();
}

void fast_1s_timer()
{
    cli();
    TCCR1A = 0;
    TCCR1B = 0;
    TCNT1  = 0;
    OCR1A  = TIME_PRESCALER_250ms;
    TIFR1  = (1<<OCF1A);
    TCCR1B = (1<<WGM12)|(1<<CS12);
    TIMSK1 |= (1<<OCIE1A);
    sei();
}

void disable_1s_timer()
{
    cli();
    TIMSK1 &= ~(1<<OCIE1A);
    TCCR1B &= ~((1<<CS12)|(1<<CS11)|(1<<CS10)); // stop Timer1 clock
    TIFR1 = (1<<OCF1A);
    sei();
}

void deconf_regs()
{
    TCCR0B=0; TCCR0A=0; OCR0A=0;
    TCCR1B=0; OCR1A=0;
    TIMSK0=0; TIMSK1=0;
    OCR2A=0;  TCCR2A=0; TCCR2B=0;
    ADMUX=0;  ADCSRA=0;
    PORTB=0;  DDRB=0;
    INHIBIT_DDR  |= (1<<INHIBIT_PIN);
    INHIBIT_PORT |= (1<<INHIBIT_PIN);
    FAN_DDR  |= (1<<FAN_PIN);
    FAN_PORT |= (1<<FAN_PIN);
}

/** Print from PROGMEM **/
void lcd_print_pmem(const char *data, uint8_t len)
{
    for (int n = 0; n < len; n++) buf[n] = pgm_read_byte_near(data + n);
    lcd_sendstring(buf, len);
}

void lcd_print_pmem_setpos(const char *data, uint8_t len, uint8_t column, uint8_t line)
{
    for (int n = 0; n < len; n++) buf[n] = pgm_read_byte_near(data + n);
    lcd_setcursor(column, line);
    lcd_sendstring(buf, len);
}

uint8_t get_buttons()
{
    uint8_t btns = (buttons ^ buttons_old) & buttons;
    buttons_old = buttons;
    return btns;
}

// ─── String / display helpers ────────────────────────────────────────────────

void mAh_string(char *buf)
{
    buf[0]=dig32_7(mAh100); buf[1]=dig32_6(mAh100); buf[2]=dig32_5(mAh100);
    buf[3]=dig32_4(mAh100); buf[4]=dig32_3(mAh100); buf[5]=dig32_2(mAh100);
    buf[6]='.'; buf[7]=dig32_1(mAh100); buf[8]=dig32_0(mAh100);
}

void mWh_string(char *buf)
{
    unsigned long long mWh = mWsx10 / 36000ULL;
    buf[0]=dig32_7(mWh); buf[1]=dig32_6(mWh); buf[2]=dig32_5(mWh);
    buf[3]=dig32_4(mWh); buf[4]=dig32_3(mWh); buf[5]=dig32_2(mWh);
    buf[6]=dig32_1(mWh); buf[7]=dig32_0(mWh); buf[8]=' ';
}
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

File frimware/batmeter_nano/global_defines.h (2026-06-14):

/**
    Battery analyzer - Arduino Nano port
    Original: (c) 2016-2017 F. Štefanec
**/

#ifndef GLOBAL_DEFINES_H_INCLUDED
#define GLOBAL_DEFINES_H_INCLUDED

// ─── Button masks ─────────────────────────────────────────────────────────────
#define BTN_ESC   128
#define BTN_UP     64
#define BTN_DOWN   32
#define BTN_OK     16

// ─── Status byte (stat) bit flags ────────────────────────────────────────────
#define stat_disch_enabled    128
#define stat_display_prog      64
#define stat_term_wait         32
#define stat_inside_menu       16
#define stat_rin_test           8
#define stat_inside_submenu     4
#define stat_ccload_enabled     2
#define stat_ccload_display     1

// ─── Status byte 2 (stat2) ───────────────────────────────────────────────────
#define stat2_redraw_menu  128

// ─── Settings byte ───────────────────────────────────────────────────────────
#define settings_sound_on  128

// ─── Timer 1 compare values ──────────────────────────────────────────────────
// Arduino Nano hardware clock is 16 MHz.  Use the real hardware clock here,
// not F_CPU, because an accidentally selected 4 MHz board profile makes the
// elapsed-time counter run 4× too fast.
#define HW_CPU_HZ              16000000UL
#if (F_CPU != HW_CPU_HZ)
#warning "Battery Analyzer Nano firmware expects a 16 MHz Arduino Nano board profile"
#endif
#define TIME_PRESCALER_1000ms  ((uint16_t)(HW_CPU_HZ/256UL - 1UL))       // 62499
#define TIME_PRESCALER_250ms   ((uint16_t)(HW_CPU_HZ/256UL/4UL - 1UL))   // 15624

// ─── Voltage limits ───────────────────────────────────────────────────────────
// Values are stored in 0.01 V units.  300 = 3.00 V.
// For a single 18650 Li-ion cell, 3.00 V is a safe default cutoff.
// The menu is clamped to 2.50–4.20 V to prevent accidental deep discharge.
#define MIN_VOLTAGE   80
#define MAX_VOLTAGE 2000
#define DEFAULT_TERM_VOLTAGE 300
#define MIN_TERM_VOLTAGE     250
#define MAX_TERM_VOLTAGE     420

#endif // GLOBAL_DEFINES_H_INCLUDED

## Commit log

2026-06-14 Add files via upload
    Initial project upload
    [sprint-layout-6-pcb-file.DRL, sprint-layout-6-pcb-file_copper_bottom.gbr, sprint-layout-6-pcb-file_copper_top.gbr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]
2026-06-14 Remove duplicate nested folder
    [sprint-layout-6-pcb-file.DRL, sprint-layout-6-pcb-file_copper_bottom.gbr, sprint-layout-6-pcb-file_copper_top.gbr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]
2026-06-16 Update README.md
    add new schematic
